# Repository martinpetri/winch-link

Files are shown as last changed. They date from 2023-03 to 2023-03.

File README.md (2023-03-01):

# winch-link

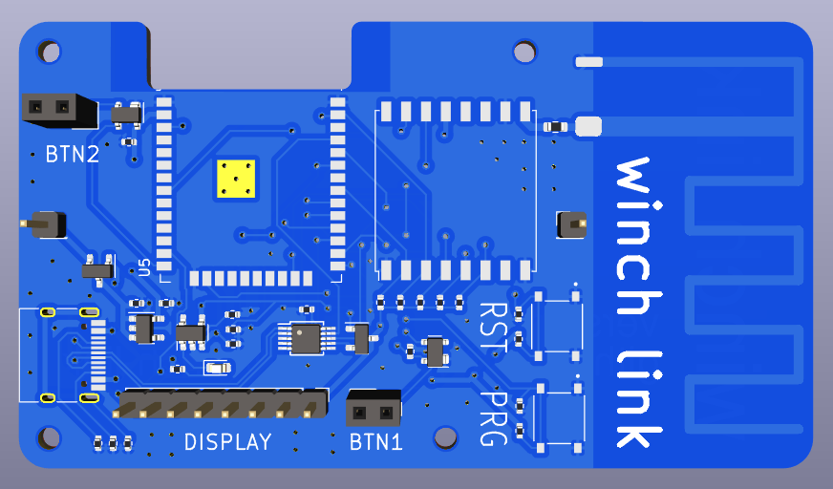
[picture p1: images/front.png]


This is a new project and intended to facilitate communication when launching a paraglider with a winch, as the usual communication via radio often causes problems.

This requires one device for the launch leader and one for the winch.
"winch link" is to transmit the different states like "pilot ready to launch", "pilot hooked in", "tighten rope" etc. to the winch by pressing a button. The winch operator can set his device to confirm automatically or by pressing a button.

Currently the device is under development (See [hardware/winch-link](hardware/winch-link)). The circuit board is drawn and the first prototypes will be ordered in the next weeks. The device will be equipped with an e-paper display so that it can be read in direct sunlight. 

## MIT License

Copyright (c) [2023] [Martin Petri]

Permission is hereby granted, free of charge, to any person obtaining a copy
of this software and associated documentation files (the "Software"), to deal
in the Software without restriction, including without limitation the rights
to use, copy, modify, merge, publish, distribute, sublicense, and/or sell
copies of the Software, and to permit persons to whom the Software is
furnished to do so, subject to the following conditions:

The above copyright notice and this permission notice shall be included in all
copies or substantial portions of the Software.

THE SOFTWARE IS PROVIDED "AS IS", WITHOUT WARRANTY OF ANY KIND, EXPRESS OR
IMPLIED, INCLUDING BUT NOT LIMITED TO THE WARRANTIES OF MERCHANTABILITY,
FITNESS FOR A PARTICULAR PURPOSE AND NONINFRINGEMENT. IN NO EVENT SHALL THE
AUTHORS OR COPYRIGHT HOLDERS BE LIABLE FOR ANY CLAIM, DAMAGES OR OTHER
LIABILITY, WHETHER IN AN ACTION OF CONTRACT, TORT OR OTHERWISE, ARISING FROM,
OUT OF OR IN CONNECTION WITH THE SOFTWARE OR THE USE OR OTHER DEALINGS IN THE
SOFTWARE.

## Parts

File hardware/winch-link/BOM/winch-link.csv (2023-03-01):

Comment | Designator | Footprint | JLCPCB Part #
1uF | C10,C11 | Resistor_SMD:R_0402_1005Metric | C325464
4.7uF | C3,C4 | Resistor_SMD:R_0402_1005Metric | C87147
100nF | C5,C6,C7,C8,C9 | Resistor_SMD:R_0402_1005Metric | C338032
LED_Small | D1 | LED_SMD:LED_0603_1608Metric | C2286
BAT54C | D3 | Package_TO_SOT_SMD:SOT-23 | C171429
USB_C_Receptacle_USB2.0 | J1 | Connector_USB:USB_C_Receptacle_HRO_TYPE-C-31-M-12 | C167321
AO3401A | Q1 | Package_TO_SOT_SMD:SOT-23 | AO3401A
5.11k | R1,R3 | Resistor_SMD:R_0402_1005Metric | C103084
470 | R10 | Resistor_SMD:R_0402_1005Metric | C114877
0R | R13 | Resistor_SMD:R_0603_1608Metric | C21189
1M | R2 | Resistor_SMD:R_0402_1005Metric | C269676
10k | R4,R5,R6,R7,R8,R11,R12 | Resistor_SMD:R_0402_1005Metric | C406733
2k | R9 | Resistor_SMD:R_0402_1005Metric | C409711
RST | SW1 | TS-1187A-B-A-B:SW_TS-1187A-B-A-B | C318889
PRG | SW2 | TS-1187A-B-A-B:SW_TS-1187A-B-A-B | C318889
RFM95W-868S2 | U1 | RF_Module:HOPERF_RFM9XW_SMD | C2844472
MCP73831-2-OT | U2 | Package_TO_SOT_SMD:SOT-23-5 | C424093
CH340E | U3 | Package_SO:MSOP-10_3x3mm_P0.5mm | C99652
ESP32-WROOM-32D | U5 | RF_Module:ESP32-WROOM-32D | C473012
MAX6816 | U6,U7 | Package_TO_SOT_SMD:SOT-143 | C41637
ME6211C33M5GN | U8 | ME6211:SOT-23-5 | C82942

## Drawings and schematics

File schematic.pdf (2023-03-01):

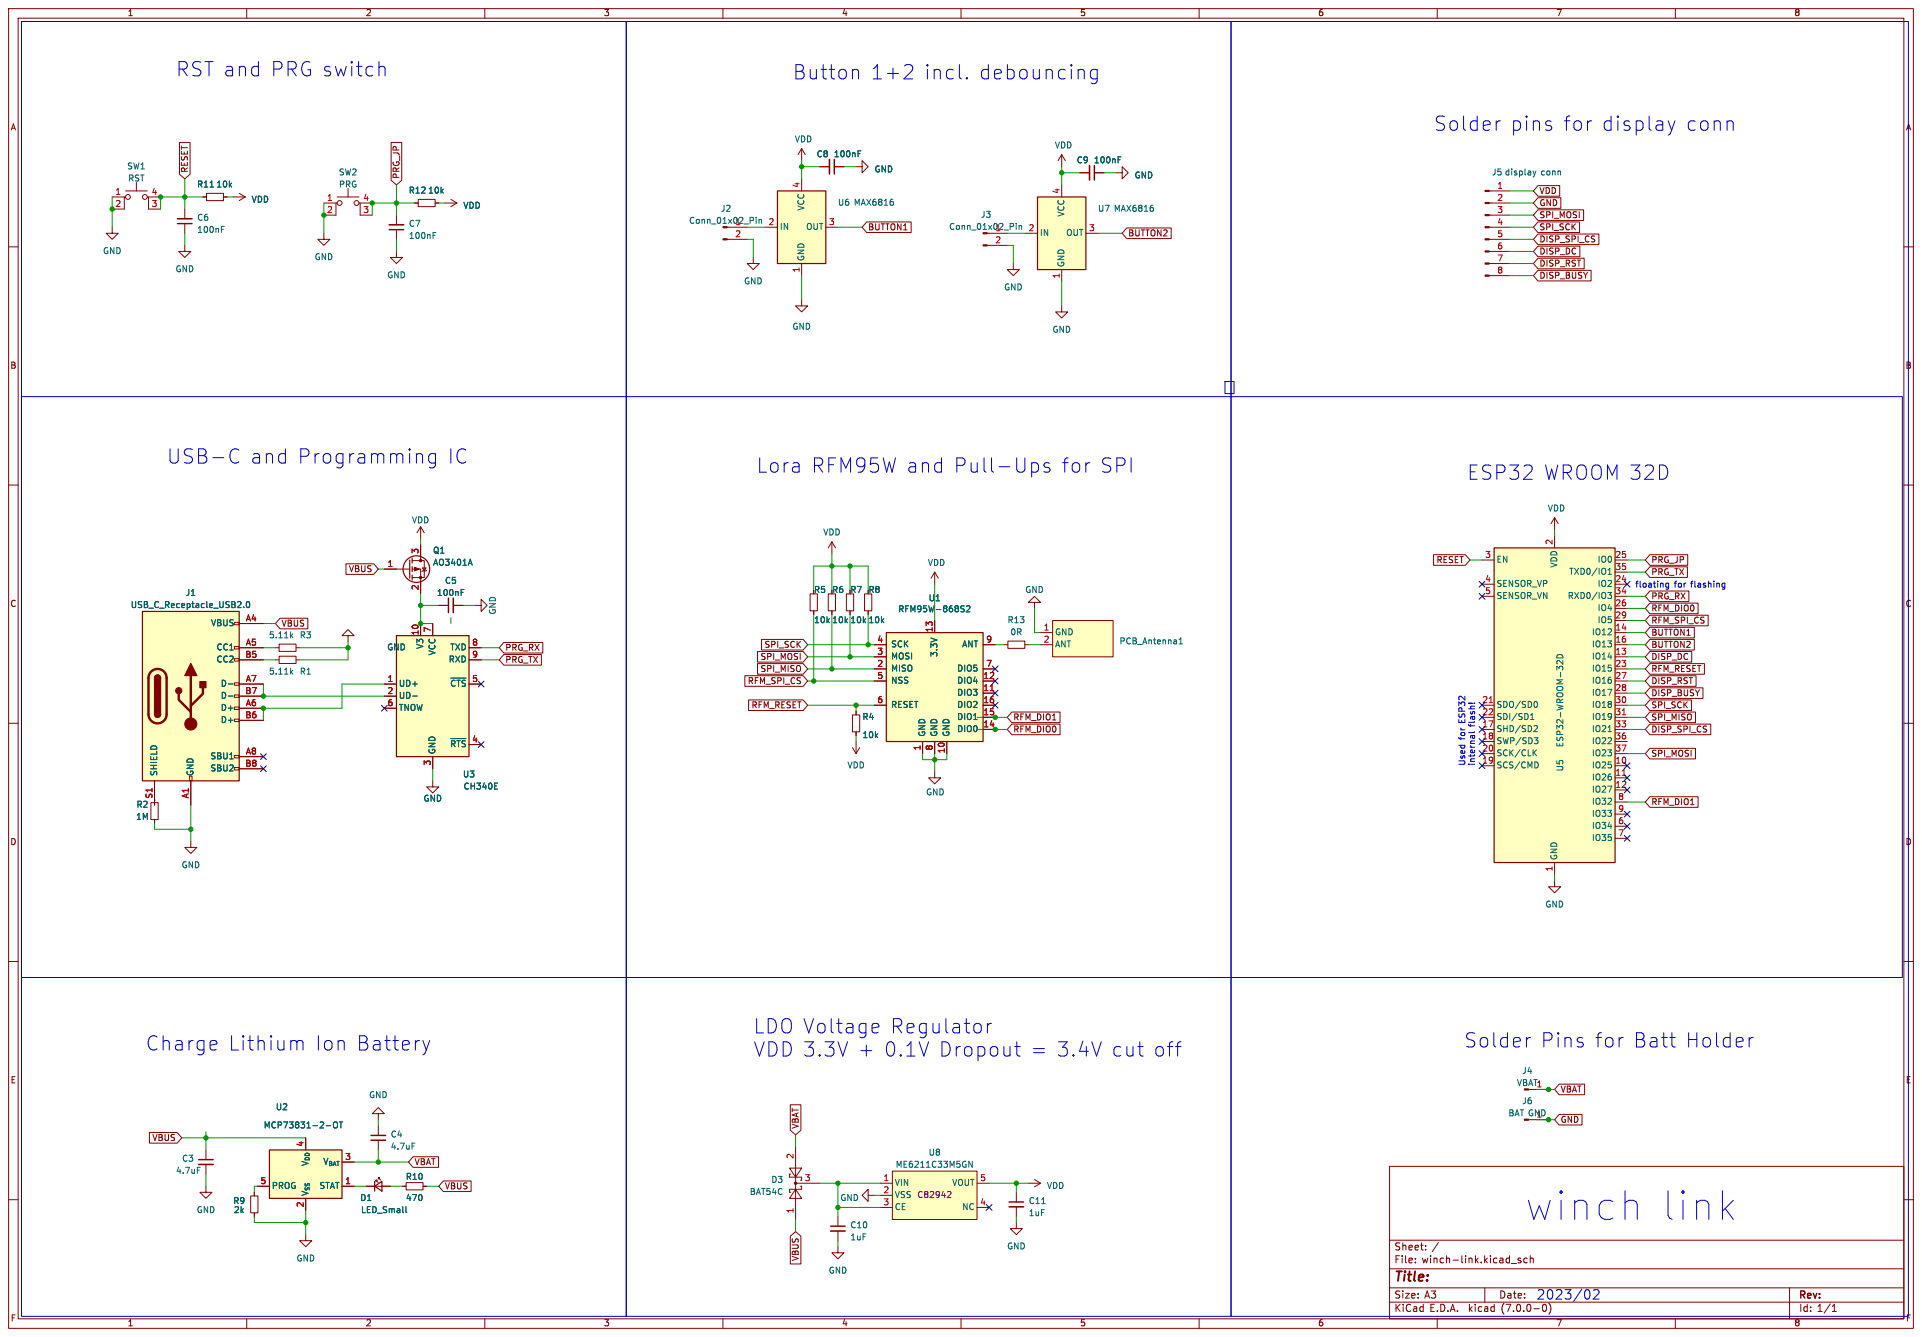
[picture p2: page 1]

Solder pins for display conn
PRG_RX DISP_BUSY

ESP32 WROOM 32D Used for ESP32 internal flash!

2 SCK/CLK 20 SDO/SD0 21 SDI/SD1 22

1 GND 10 DIO3 11 DIO4 12 3.3V 13 DIO0 14 DIO1 15 DIO2 16 MISO 2 MOSI 3 SCK 4 NSS 5 RESET 6 DIO5 7 GND

3 ~{RTS}4 ~{CTS}5 TNOW 6 VCC

LDO Voltage Regulator
VDD 3.3V + 0.1V Dropout = 3.4V cut off

Charge Lithium Ion Battery

Solder Pins for Batt Holder

Id: 1/1 Title: File: winch-link.kicad_sch Sheet: /

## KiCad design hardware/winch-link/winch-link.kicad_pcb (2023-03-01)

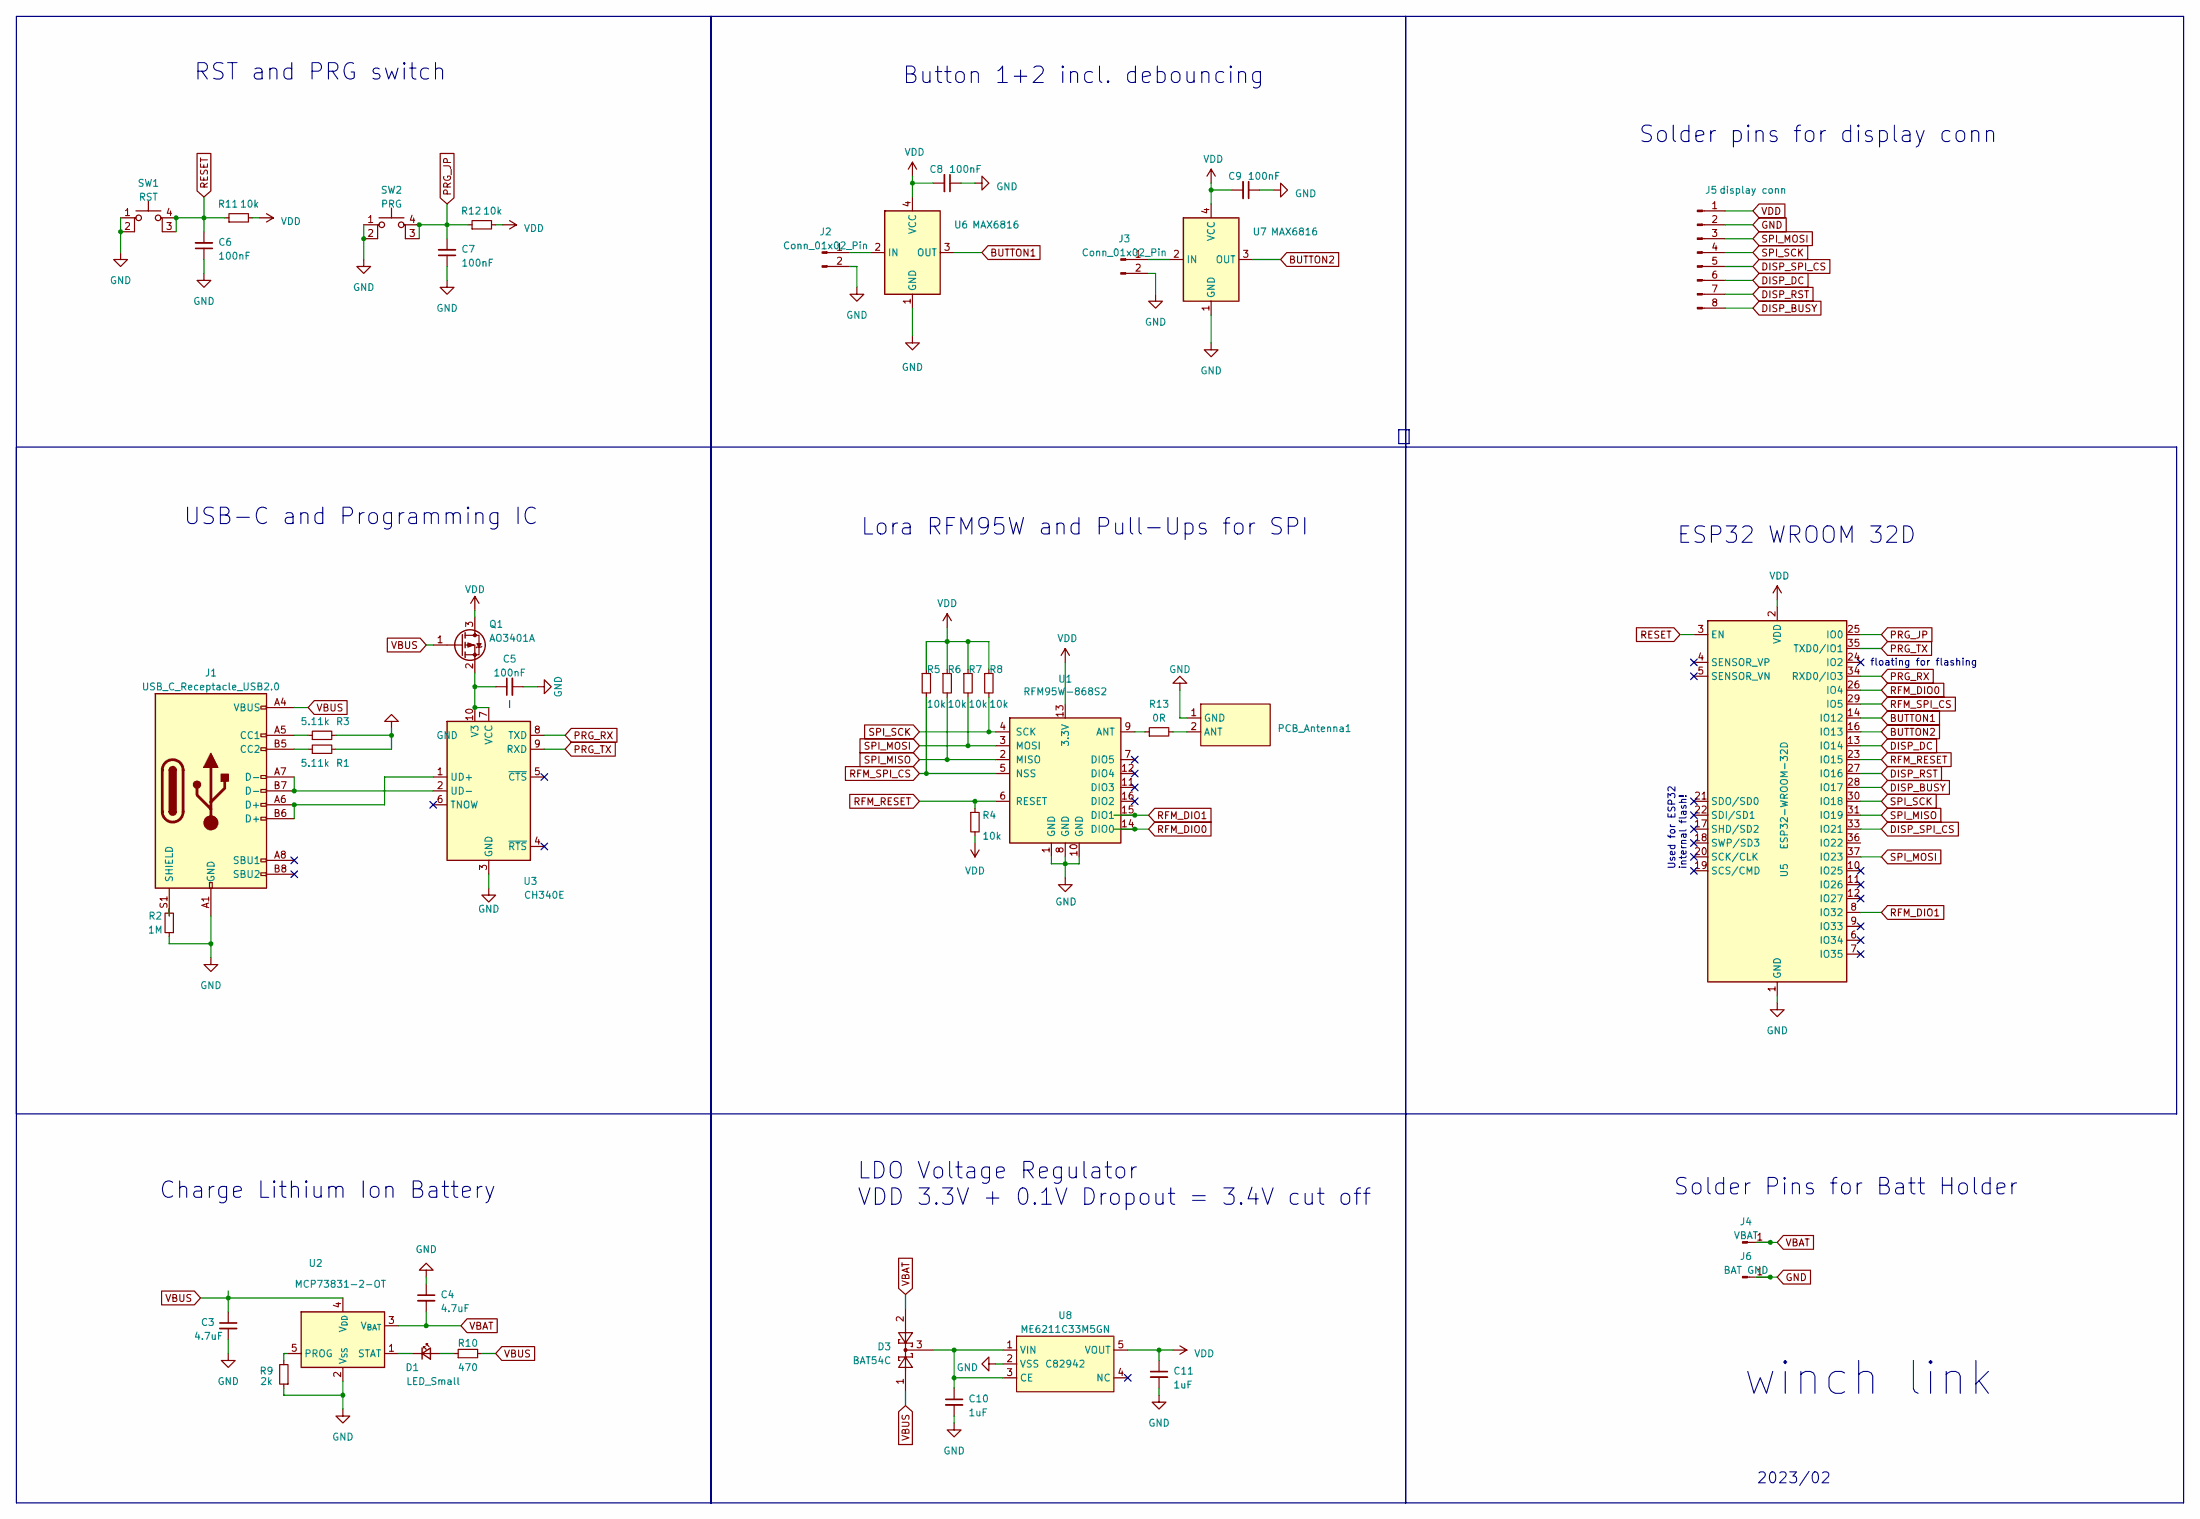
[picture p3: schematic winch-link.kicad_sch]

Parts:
C3, C4: 4.7uF; R_0402_1005Metric; LCSC C87147
C5, C6, C7, C8, C9: 100nF; R_0402_1005Metric; LCSC C338032
C10, C11: 1uF; R_0402_1005Metric; LCSC C325464
D1: LED_Small; LED_0603_1608Metric; LCSC C2286
D3: BAT54C; SOT-23; LCSC C171429
J1: USB_C_Receptacle_USB2.0; USB_C_Receptacle_HRO_TYPE-C-31-M-12; LCSC C167321
J2, J3: Conn_01x02_Pin; PinSocket_1x02_P2.54mm_Vertical
J4: VBAT; PinHeader_1x01_P2.54mm_Vertical
J5: display conn; PinHeader_1x08_P2.54mm_Vertical
J6: BAT GND; PinHeader_1x01_P2.54mm_Vertical
PCB_Antenna1: pcb antenna
Q1: AO3401A; SOT-23; LCSC AO3401A
R1, R3: 5.11k; R_0402_1005Metric; LCSC C103084
R2: 1M; R_0402_1005Metric; LCSC C269676
R4, R5, R6, R7, R8, R11, R12: 10k; R_0402_1005Metric; LCSC C406733
R9: 2k; R_0402_1005Metric; LCSC C409711
R10: 470; R_0402_1005Metric; LCSC C114877
R13: 0R; R_0603_1608Metric; LCSC C21189
SW1: RST; SW_TS-1187A-B-A-B; LCSC C318889
SW2: PRG; SW_TS-1187A-B-A-B; LCSC C318889
U1: RFM95W-868S2; HOPERF_RFM9XW_SMD; LCSC C2844472
U2: MCP73831-2-OT; SOT-23-5; LCSC C424093
U3: CH340E; MSOP-10_3x3mm_P0.5mm; LCSC C99652
U5: ESP32-WROOM-32D; LCSC C473012
U6, U7: MAX6816; SOT-143; LCSC C41637
U8: ME6211C33M5GN; SOT-23-5; LCSC C82942

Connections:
BUTTON1: U5.14 (IO12), U6.3 (OUT)
BUTTON2: U5.16 (IO13), U7.3 (OUT)
DISP_BUSY: J5.8, U5.28 (IO17)
DISP_DC: J5.6, U5.13 (IO14)
DISP_RST: J5.7, U5.27 (IO16)
DISP_SPI_CS: J5.5, U5.33 (IO21)
GND: C3.2, C4.1, C5.2, C6.1, C7.1, C8.1, C9.1, C10.2, C11.2, J1.A1 (GND), J1.A12 (GND), J1.B1 (GND), J1.B12 (GND), J2.2, J3.2, J5.2, J6.1, PCB_Antenna1.1 (GND), R1.2, R2.1, R3.2, R9.1, SW1.1, SW1.2, SW2.1, SW2.2, U1.1 (GND), U1.8 (GND), U1.10 (GND), U2.2 (V_{SS}), U3.3 (GND), U5.1 (GND), U5.15 (GND), U5.38 (GND), U5.39 (GND), U6.1 (GND), U7.1 (GND), U8.2 (VSS)
unnamed: D1.2 (A), R10.1
unnamed: D1.1 (K), U2.1 (STAT)
unnamed: J1.A5 (CC1), R3.1
unnamed: J1.B5 (CC2), R1.1
unnamed: J1.S1 (SHIELD), R2.2
unnamed: J2.1, U6.2 (IN)
unnamed: J3.1, U7.2 (IN)
unnamed: PCB_Antenna1.2 (ANT), R13.2
unnamed: C5.1, Q1.2 (S), U3.7 (VCC), U3.10 (V3)
unnamed: R13.1, U1.9 (ANT)
unnamed: R9.2, U2.5 (PROG)
unnamed: J1.A6 (D+), J1.B6 (D+), U3.1 (UD+)
unnamed: J1.A7 (D-), J1.B7 (D-), U3.2 (UD-)
unnamed: C10.1, D3.3, U8.1 (VIN), U8.3 (CE)
PRG_JP: C7.2, R12.1, SW2.3 (K), SW2.4 (A), U5.25 (IO0)
PRG_RX: U3.8 (TXD), U5.34 (RXD0/IO3)
PRG_TX: U3.9 (RXD), U5.35 (TXD0/IO1)
RESET: C6.2, R11.1, SW1.3, SW1.4, U5.3 (EN)
RFM_DIO0: U1.14 (DIO0), U5.26 (IO4)
RFM_DIO1: U1.15 (DIO1), U5.8 (IO32)
RFM_RESET: R4.1, U1.6 (RESET), U5.23 (IO15)
RFM_SPI_CS: R5.2, U1.5 (NSS), U5.29 (IO5)
SPI_MISO: R6.2, U1.2 (MISO), U5.31 (IO19)
SPI_MOSI: J5.3, R7.2, U1.3 (MOSI), U5.37 (IO23)
SPI_SCK: J5.4, R8.2, U1.4 (SCK), U5.30 (IO18)
VBAT: C4.2, D3.2, J4.1, U2.3 (V_{BAT})
VBUS: C3.1, D3.1, J1.A4 (VBUS), J1.A9 (VBUS), J1.B4 (VBUS), J1.B9 (VBUS), Q1.1 (G), R10.2, U2.4 (V_{DD})
VDD: C8.2, C9.2, C11.1, J5.1, Q1.3 (D), R4.2, R5.1, R6.1, R7.1, R8.1, R11.2, R12.2, U1.13 (3.3V), U5.2 (VDD), U6.4 (VCC), U7.4 (VCC), U8.5 (VOUT)

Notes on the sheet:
Lora RFM95W and Pull-Ups for SPI
2023/02
Charge Lithium Ion Battery
floating for flashing
Used for ESP32 internal flash!
Solder Pins for Batt Holder
RST and PRG switch
Solder pins for display conn
LDO Voltage Regulator VDD 3.3V + 0.1V Dropout = 3.4V cut off
ESP32 WROOM 32D
USB-C and Programming IC
Button 1+2 incl. debouncing
winch link

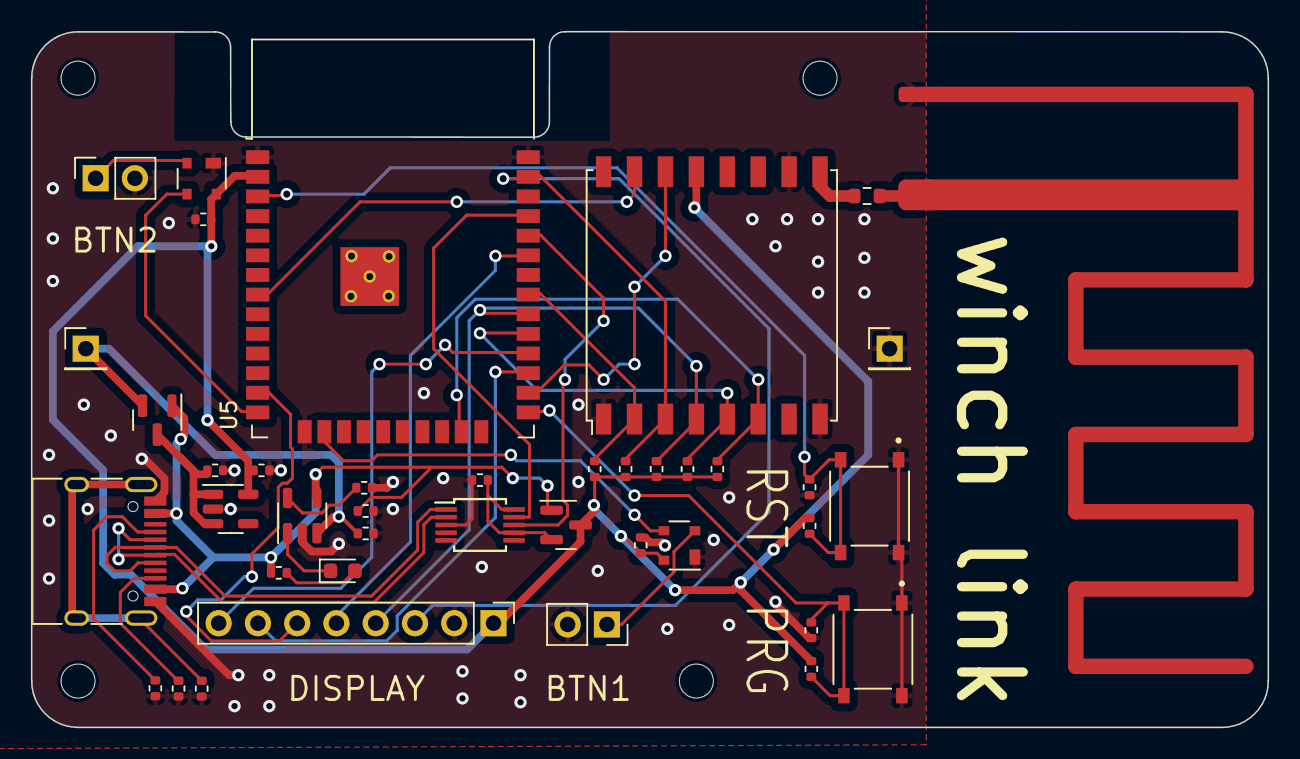
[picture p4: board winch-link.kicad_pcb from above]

Board: 2 copper layers, 80.0 x 45.0 mm, 41 parts (0 on the bottom side), 35 nets.

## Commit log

2023-02-28 first commit hardware
    [winch-link.csv, winch-link.kicad_pcb, winch-link.kicad_sch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]
2023-03-01 Add BOM and CPL files
    [winch-link-B_Cu.gbl, winch-link-B_Mask.gbs, winch-link-B_Paste.gbp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]
2023-03-01 Add README.md
    [winch-link.kicad_pcb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]
2023-03-01 Add schematic.pdf
